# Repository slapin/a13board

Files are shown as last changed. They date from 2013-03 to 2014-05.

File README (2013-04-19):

Copyright (C) 2013 Sergey Lapin

These schematics and PCB layout are free: you can redistribute it
and/or modify it under the terms of the GNU General Public License
as published by the Free Software Foundation, either version 3
of the License, or (at your option) any later version.

This schematic and PCB layout are distributed in the hope that these
will be useful, but WITHOUT ANY WARRANTY; without even the implied
warranty of MERCHANTABILITY or FITNESS FOR A PARTICULAR PURPOSE.
See the GNU General Public License for more details.

You should have received a copy of the GNU General Public License
along with this program.  If not, see <http://www.gnu.org/licenses/>.

Please note, that this license is only for schematics and board layout,
and symbol libraries.
I don't know, and I don't want to know of any patent issues you can get
into using this design. Good luck.

Also, `sexpdata` is licensed under the terms of the BSD 2-Clause License.
See the source code for more information.

Symbol for Allwinner A13 was taken from Olimex PCB for OLinuXino,
and is subject to their license and permissions.
See https://github.com/OLIMEX/OLINUXINO

S.

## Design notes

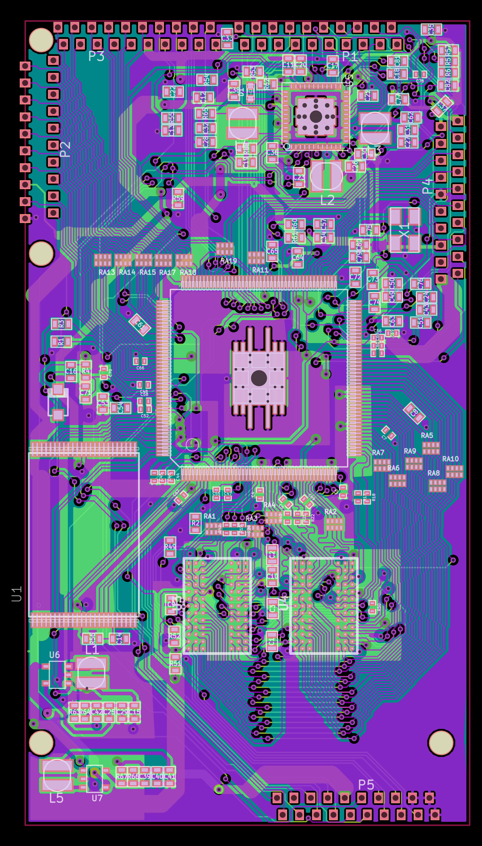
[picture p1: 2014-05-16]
png/pcb.png

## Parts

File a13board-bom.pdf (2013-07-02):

a13board.csv

Page 1

Идентификатор Элемент Корпус | Количество | Номинал
1 P6,P9,P7,P81pin | 4 CONN_1
2 D2 | SOD123 | 1 1N5819(S4SOD-123)
3 D1 | LED-0603 | 1 LED/0603
4 C3,C2,C1 SM0603_Capa | 3 100nF
5 U6,U7 | SOT23-5 | 2 SY8008BAAC
6 L5,L1,L2,L4,L3CD32 | 5 2.2uH/1.5A/DCR<0.1R/CD32
7 R17,R18,R19,R20,R22,R42,R43,R2 SM0402 | 8 22R
8 R50 | SM0402 | 1 240R/1%
9 C5,C6,C60,C61,C56,C69,C52,C45 SM0402 | 13 100nF
10 C78,C59,C68,C46,C48 SM0402 | 5 10uF/6.3V
11 C66,C58,C44SM0402 | 3 22uF/6.3V
12 C70 | SM0402 | 1 1uF
13 X1 | C5032 | 1 CRYSTAL4
14 C53,C20,C38,C13,C12,C11,C82,C SM0603A | 21 10uF/6.3V
15 C16 | SM0603A | 1 NA(22uF/6.3V)
16 C15,C10,C9,C81,C8,C54,C65,C64 SM0603A | 12 100nF
17 C14 | SM0603A | 1 NA(100nF)
18 C18,C17,C51,C32 SM0603A | 4 1uF
19 C19,C74,C72,C75,C73,C30,C31,C SM0603A | 8 1nF
20 C79,C80 | SM0603A | 2 33pF
21 C77 | SM0603A | 1 3.3nF
22 C63,C40,C41,C29,C42 SM0603A | 5 22uF/6.3V
23 C39 | SM0603A | 1 22pF
24 C25 | SM0603A | 1 47pF
25 R66 | SM0603A | 1 3.3k/1%
26 R56 | SM0603A | 1 NA(10k)
27 R62,R6,R5,R59,R60,R61,R58 SM0603A | 7 2.2k
28 R49,R53,R2 SM0603A | 3 240R/1%
29 R67 | SM0603A | 1 4.99k/1%
30 R3,R4 | SM0603A | 2 47k
31 R55,R54 | SM0603A | 2 1R
32 R1,R57 | SM0603A | 2 200k/1%
33 R65 | SM0603A | 1 0.03R/1%
34 R64 | SM0603A | 1 100k/1%
35 R63 | SM0603A | 1 22k/1%
36 R51,R52 | SM0603A | 2 2k/1%
37 P4,P2,P3,P5,P1 CONN20-1.27zzz | 5 CONN_20
38 U2 | allwinner_a13-OLIMEX_IC_TQFP176 | 1 A13
39 RA1,RA18,RA17,RA15,RA14,RA13, RN4x0402 | 17 RA4X0402
40 U1 | TSOP48 | 1 H27UBG8T2A/TSOP48
41 U4,U3 | BGA78 | 2 H5TQ2G43CFR
42 U5 | QFN48+1 | 1 OLIMEX_IC_AXP209

a13board.csv

Page 2

Supplier and ref

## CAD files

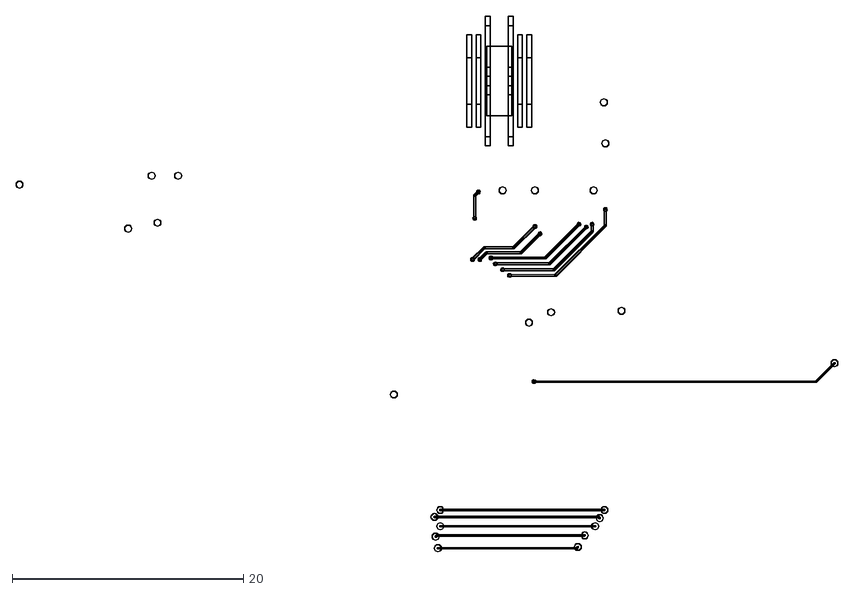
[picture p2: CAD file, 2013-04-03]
dxf/a13board-B_Cu.dxf
71.1 x 46.3

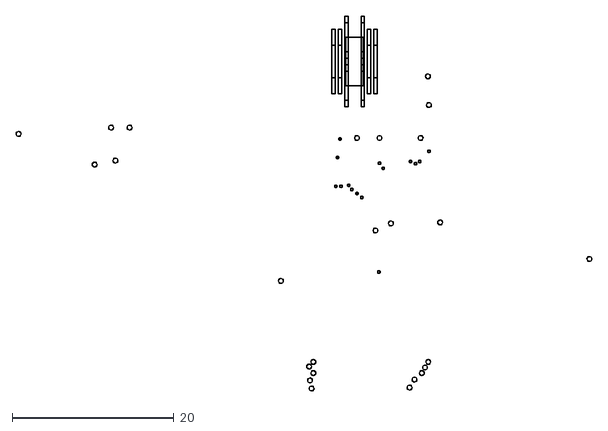
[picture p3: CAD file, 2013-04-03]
dxf/a13board-Inner2_Cu.dxf
71.1 x 46.3

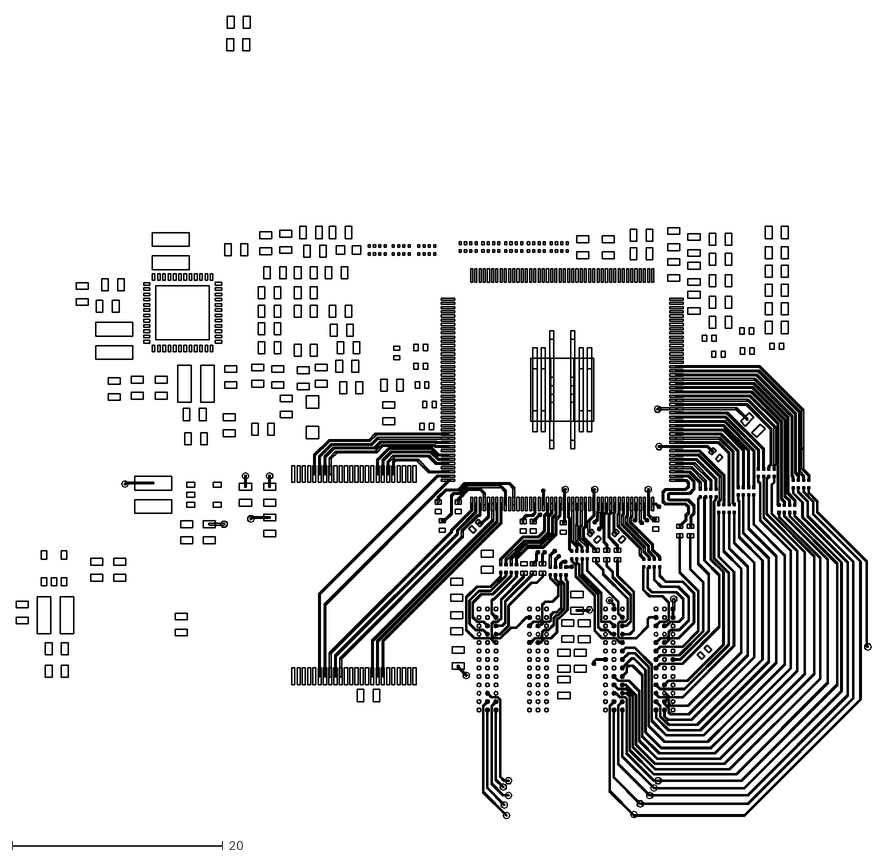
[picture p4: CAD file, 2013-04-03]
dxf/a13board-F_Cu.dxf
81.1 x 76.1

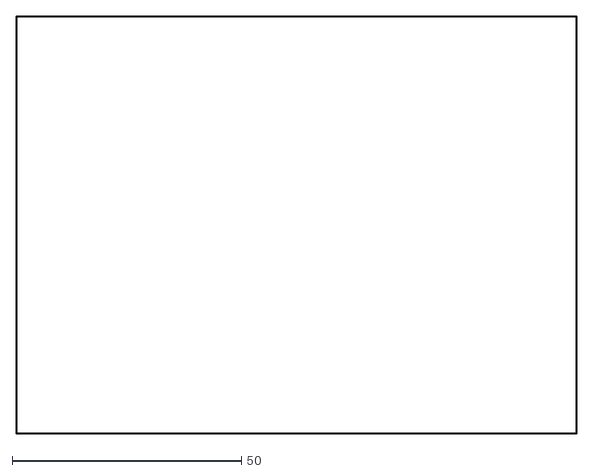
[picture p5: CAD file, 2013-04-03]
dxf/a13board-Edge_Cuts.dxf
122.5 x 91.2

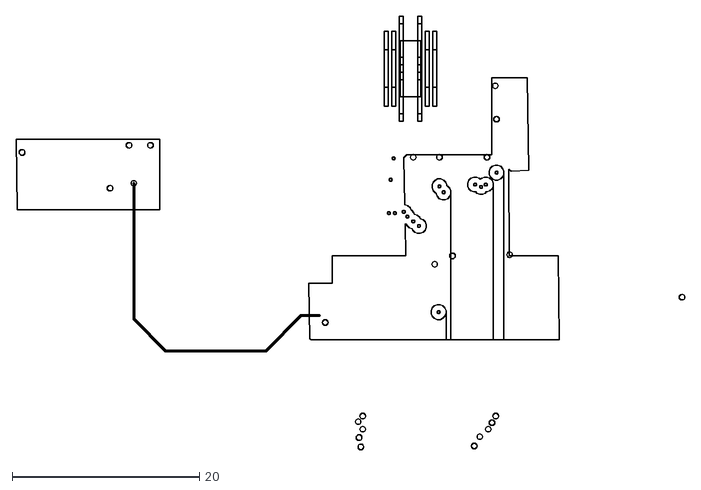
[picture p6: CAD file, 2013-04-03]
dxf/a13board-Inner1_Cu.dxf
71.4 x 46.3

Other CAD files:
dxf/a13board-F_SilkS.dxf

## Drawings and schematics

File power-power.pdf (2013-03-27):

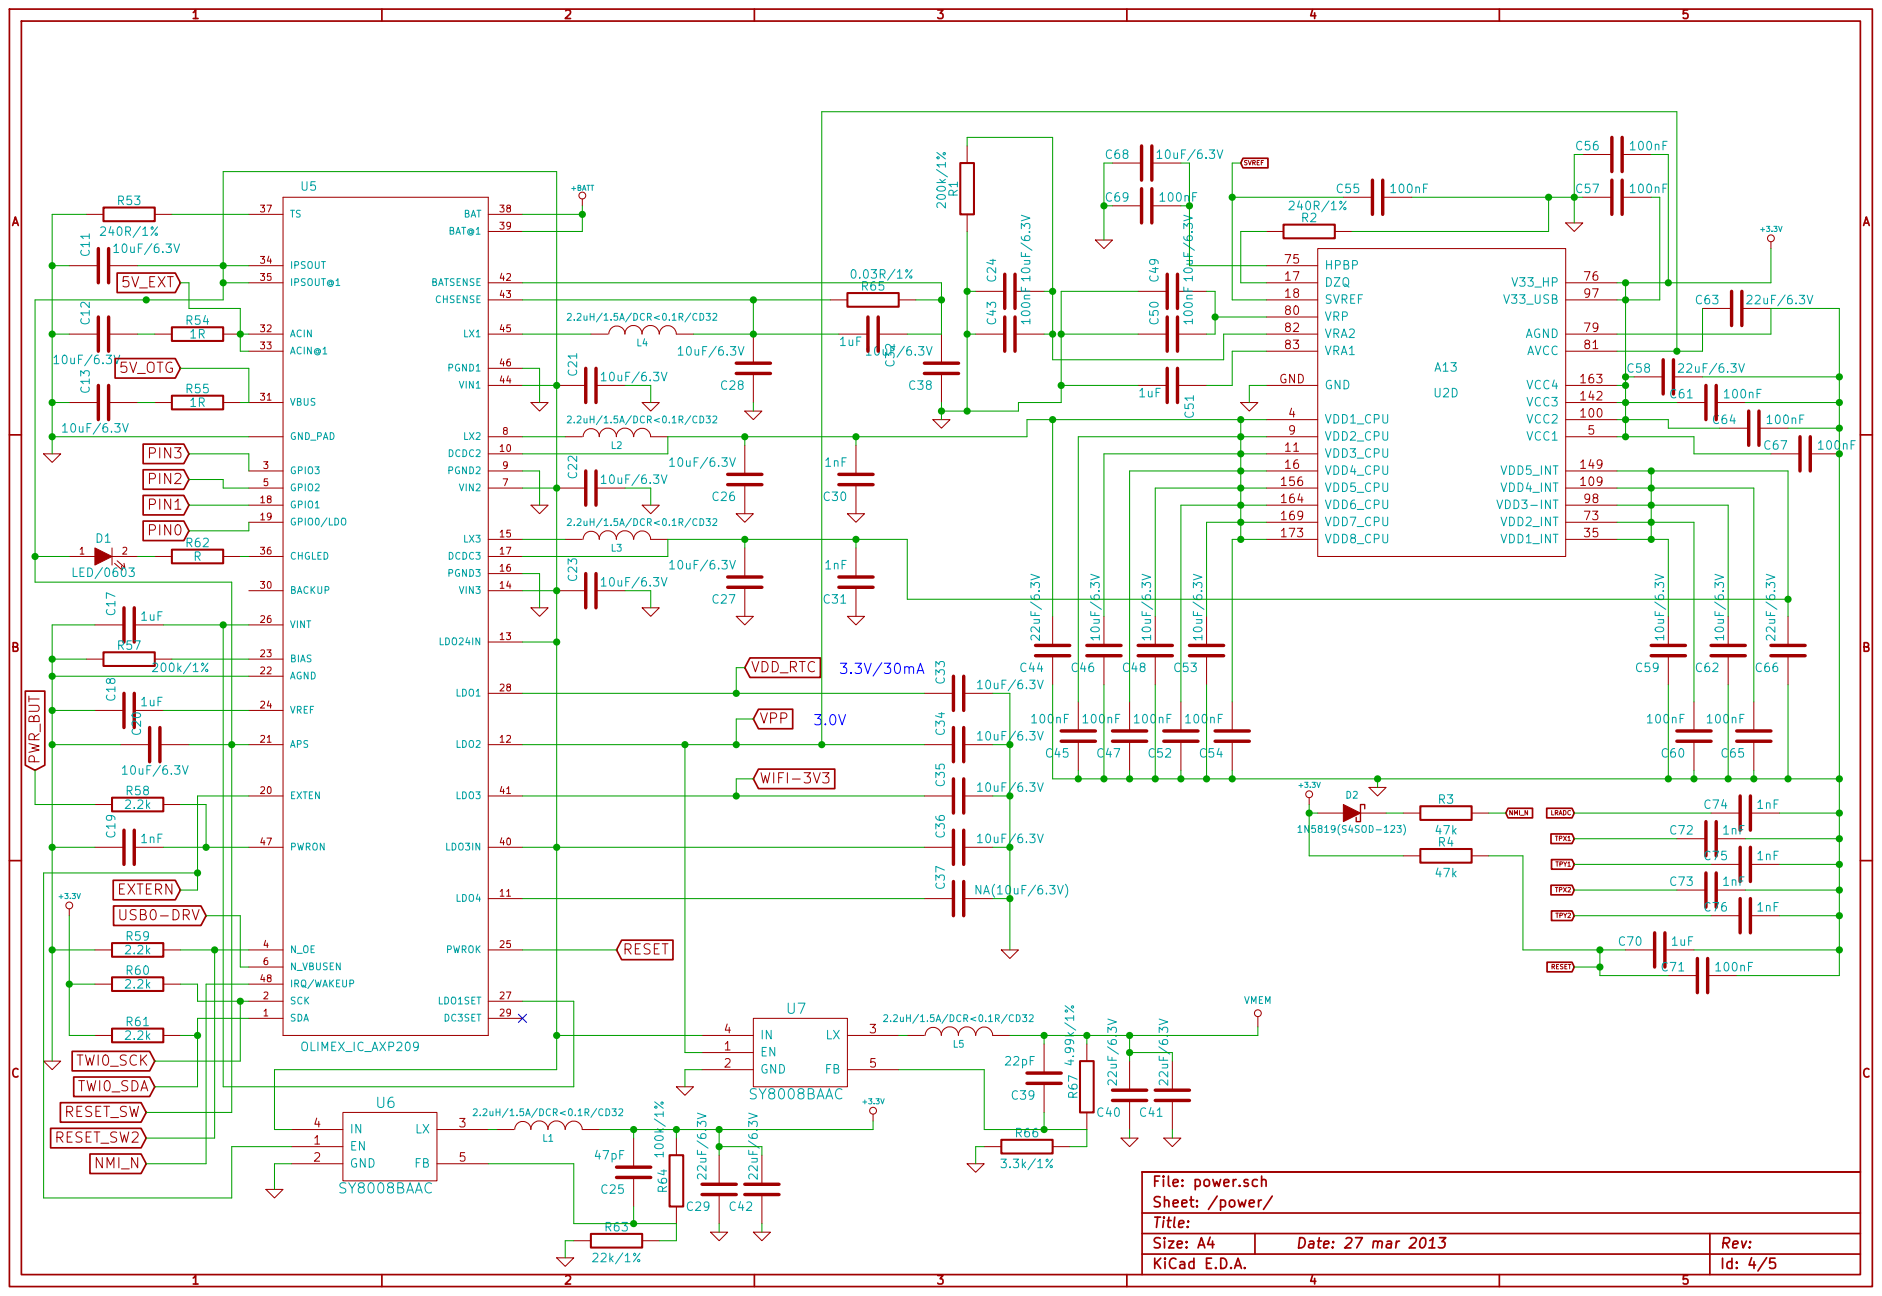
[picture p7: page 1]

RESET

EN 1 GND 2

Id: 4/5 Title: File: power.sch

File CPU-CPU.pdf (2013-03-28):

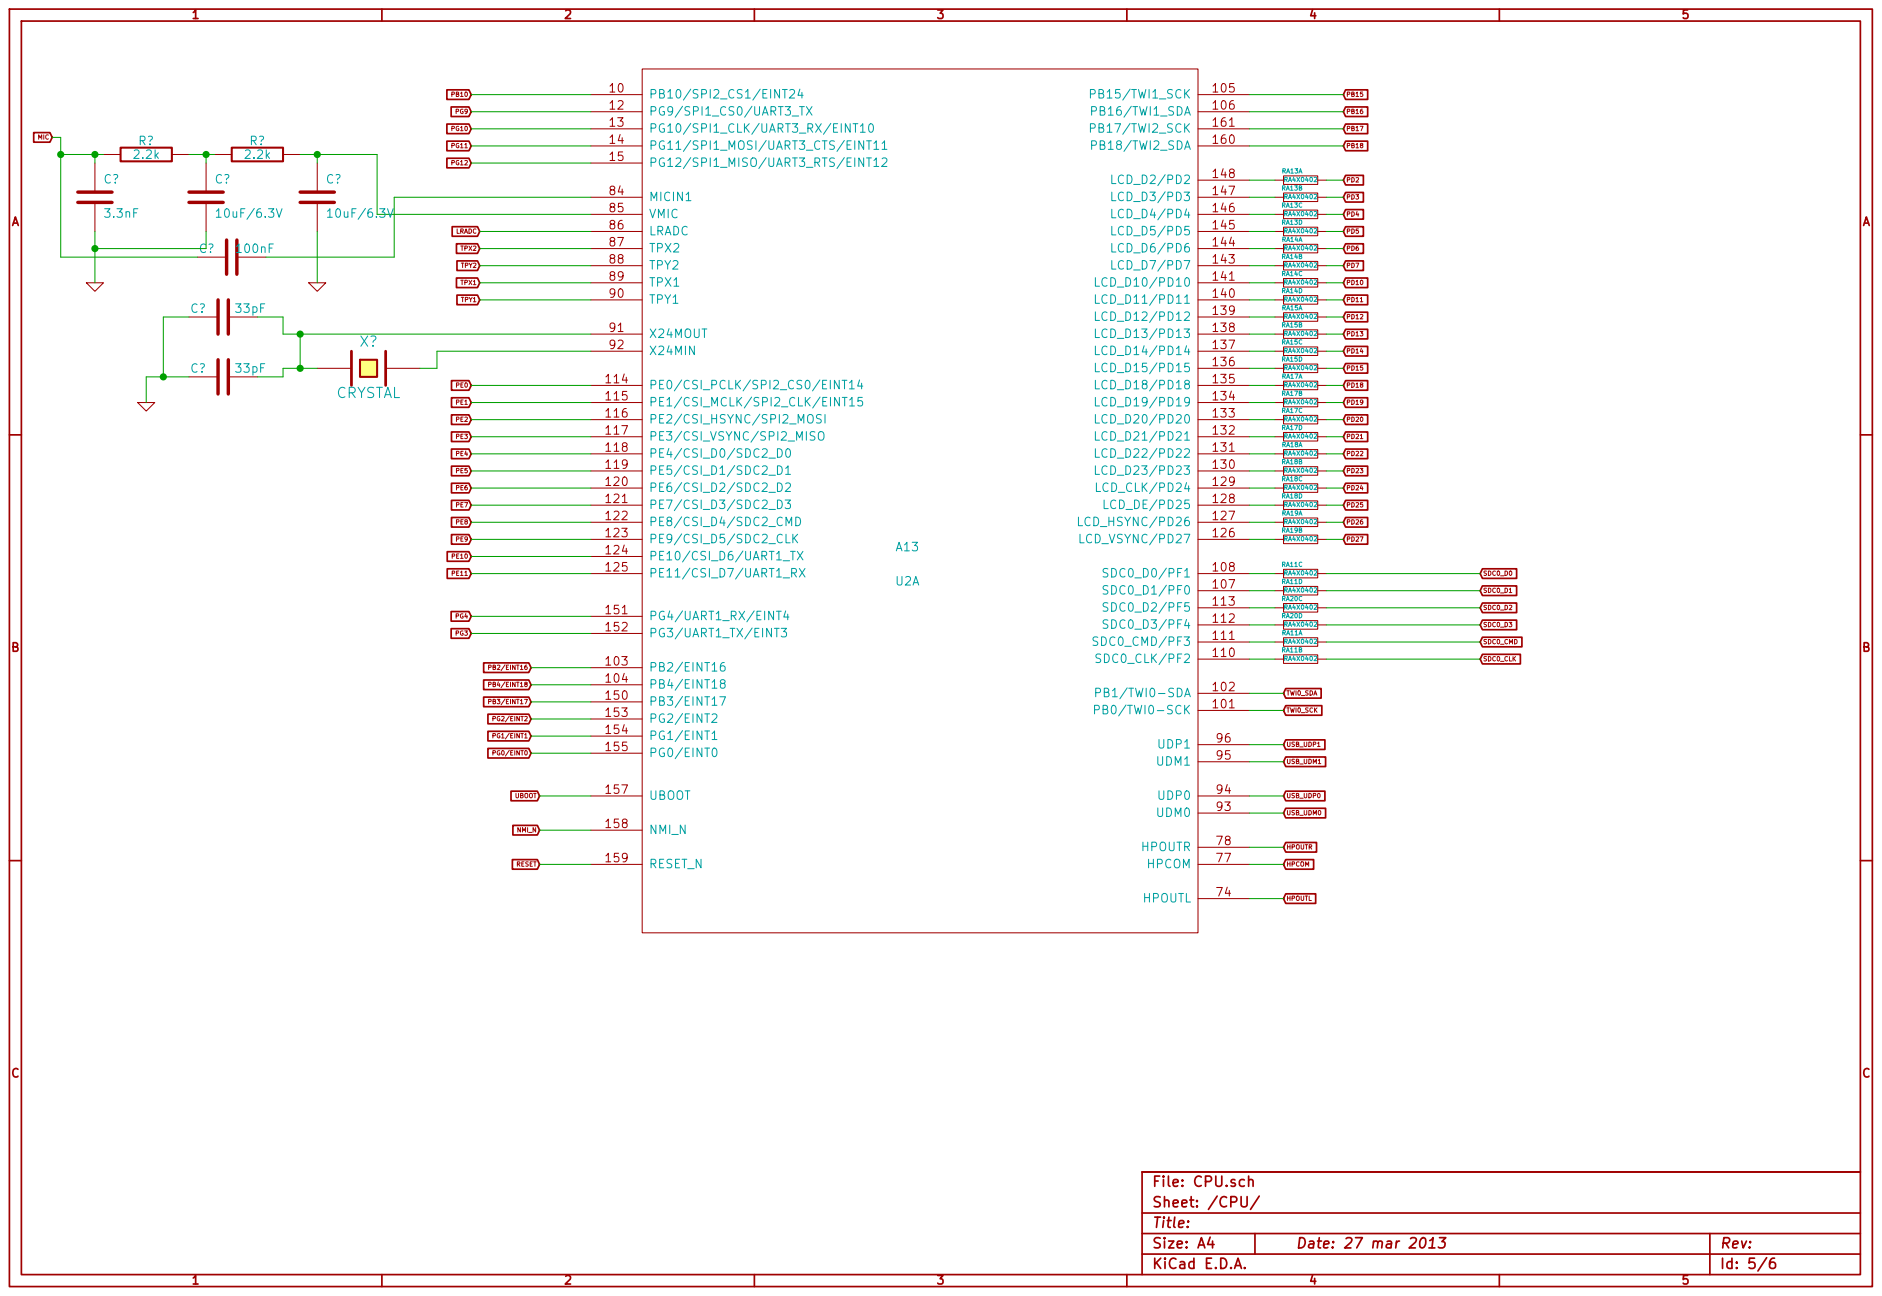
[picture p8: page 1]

Id: 5/6 Title: File: CPU.sch
Sheet: /CPU/

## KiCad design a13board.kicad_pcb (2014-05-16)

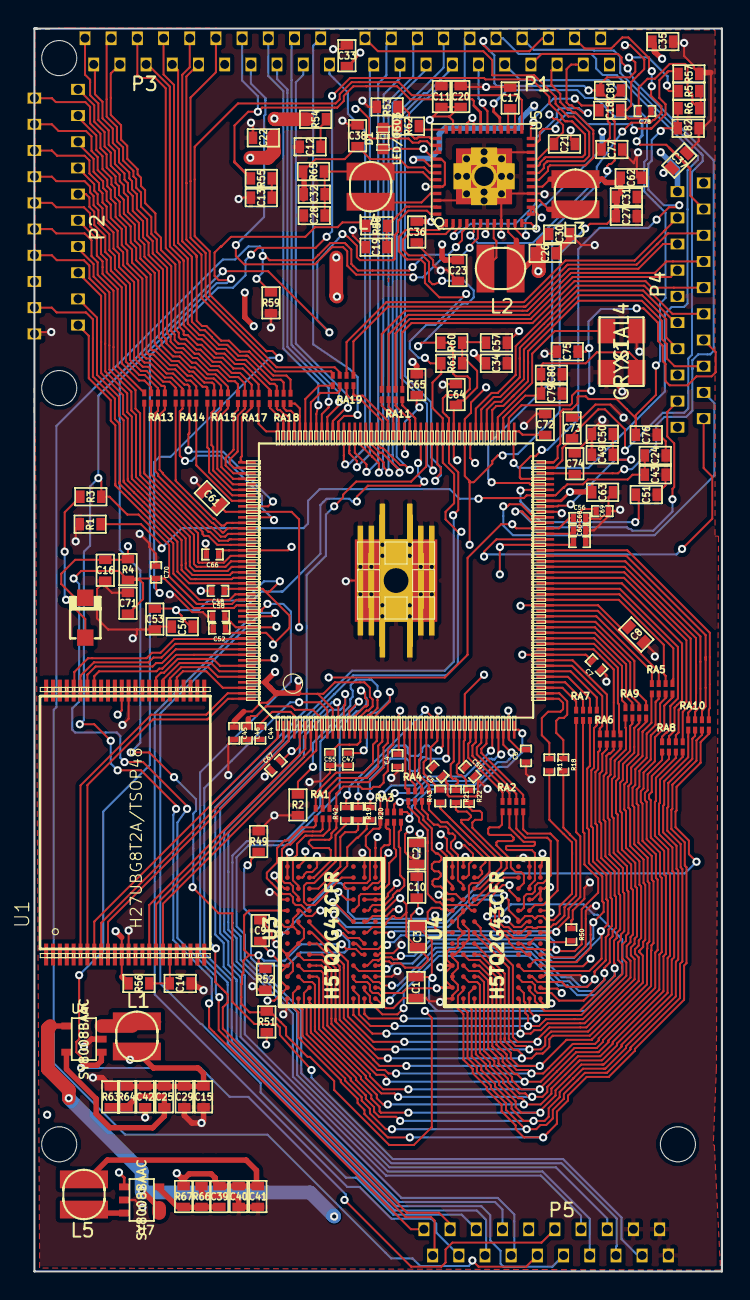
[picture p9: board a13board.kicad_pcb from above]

Board: 4 copper layers, 50.0 x 90.4 mm, 156 parts (0 on the bottom side), 271 nets.

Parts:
1PIN, 1PIN#2, 1PIN#3, 1PIN#4: P***; 1pin
C1, C2, C3: 100nF; SM0603_Capa
C4, C5, C6, C7, C45, C47, C52, C55, C56, C60, C67, C69: 100nF; SM0402
C8, C9, C10, C15, C43, C50, C54, C57, C64, C65, C71, C81: 100nF; SM0603A
C11, C12, C13, C20, C21, C22, C23, C24, C26, C27, C28, C33, C34, C35, C36, C37, C38, C49, C53, C62, C82: 10uF/6.3V; SM0603A
C14: NA(100nF); SM0603A
C16: NA(22uF/6.3V); SM0603A
C17, C18, C32, C51: 1uF; SM0603A
C19, C30, C31, C72, C73, C74, C75, C76: 1nF; SM0603A
C25: 47pF; SM0603A
C29, C40, C41, C42, C63: 22uF/6.3V; SM0603A
C39: 22pF; SM0603A
C44, C58, C66: 22uF/6.3V; SM0402
C46, C48, C59, C68, C78: 10uF/6.3V; SM0402
C61: 100nF; SM0603
C70: 1uF; SM0402
C77: 3.3nF; SM0603A
C79, C80: 33pF; SM0603A
D1: LED/0603; LED-0603
D2: 1N5819(S4SOD-123); SOD123
L1, L2, L3, L4, L5: 2.2uH/1.5A/DCR<0.1R/CD32; CD32
P1, P2, P3, P4, P5: CONN_20; CONN20-1.27zzz
R1, R57: 200k/1%; SM0603A
R2, R49, R53: 240R/1%; SM0603A
R3, R4: 47k; SM0603A
R5, R6, R58, R59, R60, R61, R62: 2.2k; SM0603A
R17, R18, R19, R20, R21, R22, R42, R43: 22R; SM0402
R50: 240R/1%; SM0402
R51, R52: 2k/1%; SM0603A
R54, R55: 1R; SM0603A
R56: NA(10k); SM0603A
R63: 22k/1%; SM0603A
R64: 100k/1%; SM0603A
R65: 0.03R/1%; SM0603A
R66: 3.3k/1%; SM0603A
R67: 4.99k/1%; SM0603A
RA1, RA2, RA3, RA4, RA5, RA6, RA7, RA8, RA9, RA10, RA11, RA13, RA14, RA15, RA17, RA18, RA19: RA4X0402; RN4x0402
U1: H27UBG8T2A/TSOP48; TSOP48
U2: A13; allwinner_a13-OLIMEX_IC_TQFP176
U3, U4: H5TQ2G43CFR; BGA78
U5: OLIMEX_IC_AXP209; QFN48+1
U6, U7: SY8008BAAC; SOT23-5
X1: CRYSTAL4; C5032

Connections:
5V_EXT: P3.9, R54.2, U5.32, U5.33
5V_OTG: P3.8, R55.2, U5.31
+3.3V: C15.1, C16.1, C25.2, C29.2, C42.2, C56.2, C57.2, C58.1, C61.1, C64.1, C67.1, D2.1, L1.2, P4.1, R4.1, R56.1, R60.1, R61.1, R64.2, U1.12, U1.37, U2.5, U2.76, U2.97, U2.100, U2.142, U2.163
+BATT: P1.20, U5.38, U5.39
/DRAM/CPU_A0: RA5.1, U2.64
/DRAM/CPU_A1: RA6.3, U2.52
/DRAM/CPU_A2: RA8.3, U2.66
/DRAM/CPU_A3: RA8.4, U2.65
/DRAM/CPU_A4: RA6.4, U2.51
/DRAM/CPU_A5: RA8.2, U2.67
/DRAM/CPU_A6: RA6.2, U2.54
/DRAM/CPU_A7: RA10.2, U2.71
/DRAM/CPU_A8: RA6.1, U2.55
/DRAM/CPU_A9: RA10.4, U2.69
/DRAM/CPU_A10: RA7.3, U2.48
/DRAM/CPU_A11: RA9.4, U2.56
/DRAM/CPU_A12: RA7.1, U2.50
/DRAM/CPU_A13: RA8.1, U2.68
/DRAM/CPU_A14: RA9.3, U2.57
/DRAM/CPU_BA0: RA5.2, U2.63
/DRAM/CPU_BA1: RA7.2, U2.49
/DRAM/CPU_BA2: RA5.3, U2.61
/DRAM/CPU_CAS: RA9.1, U2.59
/DRAM/CPU_CK: R17.2, U2.45
/DRAM/CPU_CKE: RA7.4, U2.47
/DRAM/CPU_CK_N: R18.2, U2.46
/DRAM/CPU_D0: RA1.1, U2.22
/DRAM/CPU_D1: RA3.4, U2.40
/DRAM/CPU_D2: RA1.2, U2.21
/DRAM/CPU_D3: RA3.3, U2.41
/DRAM/CPU_D4: RA1.4, U2.19
/DRAM/CPU_D5: RA3.1, U2.44
/DRAM/CPU_D6: RA1.3, U2.20
/DRAM/CPU_D7: RA3.2, U2.42
/DRAM/CPU_D8: RA2.3, U2.37
/DRAM/CPU_D9: RA4.3, U2.25
/DRAM/CPU_D10: RA2.1, U2.39
/DRAM/CPU_D11: RA4.4, U2.24
/DRAM/CPU_D12: RA2.4, U2.36
/DRAM/CPU_D13: RA4.2, U2.26
/DRAM/CPU_D14: RA2.2, U2.38
/DRAM/CPU_D15: RA4.1, U2.27
/DRAM/CPU_DM0: R42.1, U2.29
/DRAM/CPU_DM1: R43.1, U2.28
/DRAM/CPU_DQS0: R19.2, U2.31
/DRAM/CPU_DQS0_N: R20.2, U2.32
/DRAM/CPU_DQS1: R21.2, U2.33
/DRAM/CPU_DQS1_N: R22.2, U2.34
/DRAM/CPU_MEMRST: RA10.3, U2.70
/DRAM/CPU_ODT: RA10.1, U2.72
/DRAM/CPU_RAS: RA9.2, U2.58
/DRAM/CPU_WE: RA5.4, U2.60
/DRAM/DDR3_A0: RA5.8, U3.K3, U4.K3
/DRAM/DDR3_A1: RA6.6, U3.L7, U4.L7
/DRAM/DDR3_A2: RA8.6, U3.L3, U4.L3
/DRAM/DDR3_A3: RA8.5, U3.K2, U4.K2
/DRAM/DDR3_A4: RA6.5, U3.L8, U4.L8
/DRAM/DDR3_A5: RA8.7, U3.L2, U4.L2
/DRAM/DDR3_A6: RA6.7, U3.M8, U4.M8
/DRAM/DDR3_A7: RA10.7, U3.M2, U4.M2
/DRAM/DDR3_A8: RA6.8, U3.N8, U4.N8
/DRAM/DDR3_A9: RA10.5, U3.M3, U4.M3
/DRAM/DDR3_A10: RA7.6, U3.H7, U4.H7
/DRAM/DDR3_A11: RA9.5, U3.M7, U4.M7
/DRAM/DDR3_A12: RA7.8, U3.K7, U4.K7
/DRAM/DDR3_A13: RA8.8, U3.N3, U4.N3
/DRAM/DDR3_A14: RA9.6, U3.N7, U4.N7
/DRAM/DDR3_BA0: RA5.7, U3.J2, U4.J2
/DRAM/DDR3_BA1: RA7.7, U3.K8, U4.K8
/DRAM/DDR3_BA2: RA5.6, U3.J3, U4.J3
/DRAM/DDR3_CAS: RA9.8, U3.G3, U4.G3
/DRAM/DDR3_CK: R17.1, U3.F7, U4.F7
/DRAM/DDR3_CKE: RA7.5, U3.G9, U4.G9
/DRAM/DDR3_CK_N: R18.1, U3.G7, U4.G7
/DRAM/DDR3_D0: RA1.8, U3.B3
/DRAM/DDR3_D1: RA3.5, U3.C7
/DRAM/DDR3_D2: RA1.7, U3.C2
/DRAM/DDR3_D3: RA3.6, U3.C8
/DRAM/DDR3_D4: RA1.5, U3.E3
/DRAM/DDR3_D5: RA3.8, U3.E8
/DRAM/DDR3_D6: RA1.6, U3.D2
/DRAM/DDR3_D7: RA3.7, U3.E7
/DRAM/DDR3_D8: RA2.6, U4.C8
/DRAM/DDR3_D9: RA4.6, U4.D2
/DRAM/DDR3_D10: RA2.8, U4.E8
/DRAM/DDR3_D11: RA4.5, U4.E3
/DRAM/DDR3_D12: RA2.5, U4.C7
/DRAM/DDR3_D13: RA4.7, U4.C2
/DRAM/DDR3_D14: RA2.7, U4.E7
/DRAM/DDR3_D15: RA4.8, U4.B3
/DRAM/DDR3_DM0: R42.2, U3.B7
/DRAM/DDR3_DM1: R43.2, U4.B7
/DRAM/DDR3_DQS0: R19.1, U3.C3
/DRAM/DDR3_DQS0_N: R20.1, U3.D3
/DRAM/DDR3_DQS1: R21.1, U4.C3
/DRAM/DDR3_DQS1_N: R22.1, U4.D3
/DRAM/DDR3_ODT: RA10.8, U3.G1, U4.G1
/DRAM/DDR3_RAS: RA9.7, U3.F3, U4.F3
/DRAM/DDR3_RST: RA10.6, U3.N2, U4.N2
/DRAM/DDR3_WE: RA5.5, U3.H3, U4.H3
/NAND/NALE: U1.17, U2.7
/NAND/NAND_WP: C14.1, R56.2, U1.19
/NAND/NCE0: U1.9, U2.2
/NAND/NCE1: U1.10, U2.3
/NAND/NCLE: U1.16, U2.6
/NAND/NDQ0: U1.29, U2.174
/NAND/NDQ1: U1.30, U2.172
/NAND/NDQ2: U1.31, U2.171
/NAND/NDQ3: U1.32, U2.170
/NAND/NDQ4: U1.41, U2.168
/NAND/NDQ5: U1.42, U2.167
/NAND/NDQ6: U1.43, U2.166
/NAND/NDQ7: U1.44, U2.165
/NAND/NRB0: U1.7, U2.176
/NAND/NRB1: U1.6, U2.175
/NAND/NRE: U1.8, U2.1
/NAND/NWE: U1.18, U2.8
/power/VDD_CPU: C26.2, C30.2, C44.2, C45.2, C46.2, C47.2, C48.2, C52.2, C53.2, C54.2, L2.2, U2.4, U2.9, U2.11, U2.16, U2.156, U2.164, U2.169, U2.173, U5.10
/power/VDD_INT: C27.2, C31.2, C59.2, C60.2, C62.2, C65.2, C66.2, L3.2, U2.35, U2.73, U2.98, U2.109, U2.149, U5.17
BACKUP: P1.10, U5.30
EXTEN: P5.10, U5.20, U6.1
GND: C1.2, C2.2, C4.2, C5.2, C6.2, C7.2, C8.2, C9.2, C10.2, C11.1, C12.1, C13.1, C14.2, C15.2, C16.2, C17.1, C18.1, C19.1, C20.1, C21.2, C22.2, C23.2, C24.1, C26.1, C27.1, C28.1, C29.1, C30.1, C31.1, C33.2, C34.2, C35.2, C36.2, C37.2, C38.1, C40.1, C41.1, C42.1, C43.1, C44.1, C45.1, C46.1, C47.1, C48.1, C49.1, C50.1, C51.2, C52.1, C53.1, C54.1, C55.2, C56.1, C57.1, C58.2, C59.1, C60.1, C61.2, C62.1, C63.2, C64.2, C65.1, C66.1, C67.2, C68.1, C69.1, C70.2, C71.2, C72.2, C73.2, C74.2, C75.2, C76.2, C77.2, C78.2, C79.1, C80.1, C82.2, P2.1, P4.11, P5.1, P5.2, P5.4, R1.1, R2.2, R49.2, R50.2, R52.2, R53.1, R57.1, R59.1, R63.1, R66.1, U1.13, U1.36, U2.79, U2.GND, U3.A1, U3.A8, U3.B1, U3.B2, U3.B8, U3.C9, U3.D1, U3.D8, U3.D9, U3.F2, U3.F8, U3.H2, U3.J1, U3.J9, U3.L1, U3.L9, U3.N1, U3.N9, U4.A1, U4.A8, U4.B1, U4.B2, U4.B8, U4.C9, U4.D1, U4.D8, U4.D9, U4.F2, U4.F8, U4.H2, U4.J1, U4.J9, U4.L1, U4.L9, U4.N1, U4.N9, U5.9, U5.16, U5.22, U5.46, U5.GND, U6.2, U7.2, X1.2, X1.4
HPCOM: P4.3, U2.77
HPOUTL: P4.2, U2.74
HPOUTR: P4.4, U2.78
IPSOUT: C11.2, C20.2, C21.1, C22.1, C23.1, C36.1, D1.1, P4.5, P5.12, U5.7, U5.13, U5.14, U5.21, U5.34, U5.35, U5.40, U5.44, U6.4, U7.4
LDO4_3V3_200MA: C37.1, P4.20, U5.11
LRADC: C74.1, P1.14, U2.86
MIC: C77.1, C81.1, P1.15, R5.1
unnamed: R50.1, U4.H8
unnamed: R49.1, U3.H8
unnamed: C1.1, C2.1, C3.2, C10.1, R51.2, R52.1, U3.E1, U3.J8, U4.E1, U4.J8
unnamed: L1.1, U6.3
unnamed: L5.1, U7.3
unnamed: C25.1, R63.2, R64.1, U6.5
unnamed: C39.1, R66.2, R67.1, U7.5
unnamed: C68.2, C69.2, U2.75
unnamed: D2.2, R3.1
unnamed: C32.1, C38.2, R65.2, U5.42
unnamed: C49.2, C50.2, U2.80
unnamed: C24.2, C43.2, R1.2, U2.82
unnamed: R2.1, U2.17
unnamed: C51.1, U2.83
unnamed: L3.1, U5.15
unnamed: L4.1, U5.45
unnamed: C17.2, U5.26, U5.27
unnamed: R53.2, U5.37
unnamed: L2.1, U5.8
unnamed: R62.2, U5.36
unnamed: C12.2, R54.1
unnamed: C13.2, R55.1
unnamed: D1.2, R62.1
unnamed: R57.2, U5.23
unnamed: C18.2, U5.24
unnamed: C28.2, C32.2, L4.2, R65.1, U5.43
unnamed: C19.2, R58.2, U5.47
unnamed: RA11.1, U2.111
unnamed: RA14.3, U2.141
unnamed: RA14.2, U2.143
unnamed: RA14.1, U2.144
unnamed: RA13.4, U2.145
unnamed: RA13.3, U2.146
unnamed: RA13.2, U2.147
unnamed: RA13.1, U2.148
unnamed: RA14.4, U2.140
unnamed: RA11.2, U2.110
unnamed: RA19.1, U2.127
unnamed: RA19.2, U2.126
unnamed: RA15.1, U2.139
unnamed: RA18.4, U2.128
unnamed: RA18.3, U2.129
unnamed: RA18.2, U2.130
unnamed: RA18.1, U2.131
unnamed: RA17.4, U2.132
unnamed: RA17.3, U2.133
unnamed: RA17.2, U2.134
unnamed: RA17.1, U2.135
unnamed: RA15.4, U2.136
unnamed: RA15.3, U2.137
unnamed: RA15.2, U2.138
unnamed: C79.2, C80.2, U2.91, X1.1
unnamed: RA19.3, U2.113
unnamed: RA11.4, U2.107
unnamed: RA11.3, U2.108
unnamed: RA19.4, U2.112
unnamed: C81.2, U2.84
unnamed: C78.1, R5.2, R6.1
unnamed: C82.1, R6.2, U2.85
unnamed: U2.92, X1.3
NMI_N: P5.20, R3.2, U2.158, U5.48
PB2: P1.9, U2.103
PB3: P2.9, U2.150
PB4: P1.8, U2.104
PB10: P5.9, U2.10
PB15: P5.18, U2.105
PB16: P5.17, U2.106
PB17: P5.16, U2.161
PB18: P5.15, U2.160
PD2: P2.10, RA13.8
PD3: P2.11, RA13.7
PD4: P2.12, RA13.6
PD5: P2.13, RA13.5
PD6: P2.14, RA14.8
PD7: P2.15, RA14.7
PD10: P2.16, RA14.6
PD11: P2.17, RA14.5
PD12: P2.18, RA15.8
PD13: P2.19, RA15.7
PD14: P2.20, RA15.6
PD15: P3.20, RA15.5
PD18: P3.19, RA17.8
PD19: P3.18, RA17.7
PD20: P3.17, RA17.6
PD21: P3.16, RA17.5
PD22: P3.15, RA18.8
PD23: P3.14, RA18.7
PD24: P3.13, RA18.6
PD25: P3.12, RA18.5
PD26: P3.11, RA19.8
PD27: P3.10, RA19.7
PE0: P1.7, U2.114
PE1: P1.6, U2.115
PE2: P1.5, U2.116
PE3: P1.4, U2.117
PE4: P1.3, U2.118
PE5: P1.2, U2.119
PE6: P3.1, U2.120
PE7: P3.2, U2.121
PE8: P3.3, U2.122
PE9: P3.4, U2.123
PE10: P3.5, U2.124
PE11: P3.6, U2.125
PG0: P2.3, U2.155
PG1: P2.4, U2.154
PG2: P2.6, U2.153
PG3: P2.7, U2.152
PG4: P2.8, U2.151
PG9: P5.8, U2.12
PG10: P5.7, U2.13
PG11: P5.6, U2.14
PG12: P5.5, U2.15
PIN0: P1.1, U5.19
PIN1: P1.16, U5.18
PIN2: P1.17, U5.5
PIN3: P1.18, U5.3
PWR_BUT: P5.3, R58.1
RESET: C70.1, C71.1, P5.19, R4.2, U2.159, U5.25
RESET_SW2: P5.11, R59.2, U5.4
SDC0_CLK: P4.14, RA11.7
SDC0_CMD: P4.15, RA11.8
SDC0_D0: P4.13, RA11.6
SDC0_D1: P4.12, RA11.5
SDC0_D2: P4.17, RA19.6
SDC0_D3: P4.16, RA19.5
SVREF: C55.1, U2.18
TPX1: C72.1, P1.11, U2.89
TPX2: C73.1, P1.13, U2.87
TPY1: C75.1, P4.8, U2.90
TPY2: C76.1, P1.12, U2.88
TWI0_SCK: P5.14, R60.2, U2.101, U5.2
TWI0_SDA: P5.13, R61.2, U2.102, U5.1
UBOOT: P2.2, U2.157
USB0-DRV: P3.7, U5.6
USB_UDM0: P4.6, U2.93
USB_UDM1: P4.9, U2.95
USB_UDP0: P4.7, U2.94
USB_UDP1: P4.10, U2.96
VDD_RTC: C33.1, P4.18, U5.28
VMEM: C3.1, C4.1, C5.1, C6.1, C7.1, C8.1, C9.1, C39.2, C40.2, C41.2, L5.2, R51.1, R67.2, U2.23, U2.30, U2.43, U2.53, U2.62, U3.A2, U3.A9, U3.B9, U3.C1, U3.D7, U3.E2, U3.E9, U3.G2, U3.G8, U3.K1, U3.K9, U3.M1, U3.M9, U4.A2, U4.A9, U4.B9, U4.C1, U4.D7, U4.E2, U4.E9, U4.G2, U4.G8, U4.K1, U4.K9, U4.M1, U4.M9
VPP: C34.1, C63.1, P2.5, U2.81, U5.12, U7.1
WIFI-3V3: C35.1, P4.19, U5.41

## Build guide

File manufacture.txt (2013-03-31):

http://www.aliexpress.com/item/4-Layers-PCB-prototypes-printed-circuit-board-fabrication-10pcs-lot-Max-10cm-10cm-free-shipping-1045/483958869.html
$99

Place of Origin:
    Guangdong China (Mainland)

Min. Hole Size:
    0.3mm

Number of Layers:
    4-Layer

Model Number:
    4L

Min. Line Width:
    5mil

Brand Name:
    DIYGSM

is_customized:
    Yes

Base Material:
    FR4

Min. Line Spacing:
    5mil

Board Thickness:
    0.8-2.0 mm

Surface Finishing:
    HASL

Copper Thickness:
    1-4 OZ 

http://www.aliexpress.com/item/4-Layers-PCB-prototypes-printed-circuit-board-fabrication-10pcs-lot-Max-10cm-10cm-free-shipping-1045/460137153.html
$99

 Process	4 mil trace/space, 0.3mm hole

 Layers	4 layers
 Material	 FR4 0.062" FR4 1 oz
 Finishing	 HASL
 Soldermask	 Green LPI SMOBC
 Silkscreen	 White
 Lead time 	 3-4 work days

    Maximum 10cmx10cm area for 1 or 2 layers

    Additional charge for bottom silkscreen.

    3-4 work days leadtime

Place of Origin:
    China (Mainland)

Min. Hole Size:
    0.3mm

Min. Line Width:
    6mil

Brand Name:
    Red Board

Base Material:
    FR4

Min. Line Spacing:
    6mil

Board Thickness:
    0.8-1.6 mm

Surface Finishing:
    HASL

Copper Thickness:
    1-4 OZ 

quote: tedchen163@yahoo.com

http://www.aliexpress.com/item/PCB-board-Alunimium-based-PCB-pcb-manufacture-PCB-prototype-free-shippment-rigid-PCB/430062534.html
quote luwispcb(at)gmail.com

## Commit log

2013-03-19 Better pin placement
2013-03-19 Some more pin names
2013-03-19 added some schematics
    [DRAM.sch, NAND.sch, a13board.sch]
2013-03-20 Started drawing
    [DRAM.sch, NAND.sch, a13board.sch]
2013-03-20 Added more libraries; more advancement
    [DRAM.sch, NAND.sch, a13board.sch]
2013-03-20 still ERC errors
    [DRAM.sch, NAND.sch, a13board.sch]
2013-03-21 Proper laying out DDR3 in schematics
    [DRAM.sch, NAND.sch, a13board.sch]
2013-03-22 DDR3 is mostly captured
    [DRAM.sch, NAND.sch, a13board.sch]
2013-03-24 Finished DRAM, started power
    [DRAM.sch, NAND.sch, a13board.sch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]
2013-03-25 Power update; started CPU
    [CPU.sch, DRAM.sch, NAND.sch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]
2013-03-25 Fixed values for inductors
    [CPU.sch, DRAM.sch, NAND.sch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]
2013-03-26 added 3.3V power supply
    [CPU.sch, DRAM.sch, NAND.sch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]
2013-03-26 added resistor arrays, continue routing main CPU
    [CPU.sch, DRAM.sch, NAND.sch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]
2013-03-27 added schematic PDF
2013-03-27 Re-made A13 power part, finished power schematics
    [CPU.sch, DRAM.sch, NAND.sch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]
2013-03-28 Finished schematics, now fixing errors
    [CPU.sch, DRAM.sch, NAND.sch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]
2013-03-28 Added forgotten connectors.sch
    [connectors.sch]
2013-03-28 Added diode footprint
2013-03-28 Fixing schematics bugs
    [CPU.sch, DRAM.sch, NAND.sch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]
2013-03-28 Started making board and modules
    [a13board.kicad_pcb]
2013-03-29 fixed schematics errors, added CD32 and 4x0402 packages, started layout
    [a13board.kicad_pcb]
2013-03-29 Started tracing
    [a13board.kicad_pcb]
2013-03-31 more tracing progress
    [CPU.sch, DRAM.sch, NAND.sch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]
2013-04-01 Adding gerber files
    [a13board-B_Cu.gbl, a13board-F_Cu.gtl, a13board-F_SilkS.gto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]
2013-04-02 Re-tracing DDR3 with 4mil traces
    [a13board.kicad_pcb]
2013-04-03 Added dxf files
    [a13board-B_Cu.dxf, a13board-Edge_Cuts.dxf, a13board-F_Cu.dxf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]
2013-04-03 still routing ddr3
    [a13board.kicad_pcb]
2013-04-04 Routed ground poly and most of ddr3
    [a13board.kicad_pcb]
2013-04-04 more routing of DDR3
    [a13board.kicad_pcb]
2013-04-05 more routing of ddr3, found smaller approach, bga-escaping VMEM and GND
    [a13board.kicad_pcb]
2013-04-05 reducing space, occupied by address lines
    [a13board.kicad_pcb]
2013-04-06 Fixed some bugs with symbols, tracing continued
    [CPU.sch, DRAM.sch, NAND.sch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]
2013-04-06 Added connectors
    [a13board.kicad_pcb]
2013-04-07 Meeting 5x10 goal
    [a13board.kicad_pcb]
2013-04-08 A bit more of tracing of PCB
    [a13board.kicad_pcb]
2013-04-08 a bit improved layout
    [a13board.kicad_pcb]
2013-04-08 New gerber
    [a13board-B_Cu.gbl, a13board-F_Cu.gtl, a13board-F_SilkS.gto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]
2013-04-08 Almost all escaped from BGA
    [a13board.kicad_pcb]
2013-04-09 Connected a few more connections; BGA escape finished
    [a13board.kicad_pcb]
2013-04-09 Some more traces (for connectors)
    [a13board.kicad_pcb]
2013-04-09 Better naming for gerbers
    [a13board-B_Cu.gbl, a13board-Edge_Cuts.gbr, a13board-F_Cu.gtl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]
2013-04-09 new gerbers
    [a13board-B_Cu.gbl, a13board-Edge_Cuts.gbr, a13board-F_Cu.gtl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]
2013-04-09 Fixed thermal pad on A10
    [a13board.kicad_pcb]
2013-04-09 shiny new gerbers, fixed paste and mask
    [a13board-B_Cu.gbl, a13board-Edge_Cuts.gbr, a13board-F_Cu.gtl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]
2013-04-10 Added thermal for AXP209
    [a13board.kicad_pcb]
2013-04-10 Added better stencil support
    [a13board.kicad_pcb]
2013-04-10 Added missing footprints
    [a13board.kicad_pcb]
2013-04-10 Rearranged pins so to make tracing easier
    [CPU.sch, DRAM.sch, NAND.sch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]
2013-04-10 Using proper module for crystal, some rearrangements regarding connectors
    [a13board.kicad_pcb]
2013-04-11 Experimented with autotracer
    [a13board.kicad_pcb]
2013-04-11 Different layout for connectors
    [CPU.sch, DRAM.sch, NAND.sch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]
2013-04-11 Proper GND fill of thermal pad on AXP209
    [CPU.sch, DRAM.sch, NAND.sch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]
2013-04-15 More power traced
    [a13board.kicad_pcb]
2013-04-15 Added new crystal, changed 2 pins on connectors
    [CPU.sch, DRAM.sch, NAND.sch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]
2013-04-16 Almost finished tracing
    [a13board.kicad_pcb]
2013-04-16 New gerbers and board image
    [a13board-B_Cu.gbl, a13board-Edge_Cuts.gbr, a13board-F_Cu.gtl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]
2013-04-16 A few untraced connections left
    [a13board.kicad_pcb]
2013-04-16 All traces traced...
    [a13board.kicad_pcb]
2013-04-16 New gerber and png file
    [a13board-B_Cu.gbl, a13board-Edge_Cuts.gbr, a13board-F_Cu.gtl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]
2013-04-16 Updated to people's suggestions
    [a13board-B_Cu.gbl, a13board-Edge_Cuts.gbr, a13board-F_Cu.gtl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]
2013-04-16 Updated to proper zone fill
    [a13board-B_Cu.gbl, a13board-Edge_Cuts.gbr, a13board-F_Cu.gtl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]
2013-04-17 Updated layout with people's suggestions
    [CPU.sch, DRAM.sch, NAND.sch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]
2013-04-18 Used polygon for power pins
    [a13board.kicad_pcb]
2013-04-18 Included all layers to gerber project, improved .png
    [a13board-B_Cu.gbl, a13board-Edge_Cuts.gbr, a13board-F_Cu.gtl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]
2013-04-19 Fixed some power issues
    [a13board-B_Cu.gbl, a13board-Edge_Cuts.gbr, a13board-F_Cu.gtl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]
2013-04-19 A little fit of border clearance fixed
    [a13board.kicad_pcb]
2013-04-20 Added new gerber files and png
    [a13board-B_Cu.gbl, a13board-Edge_Cuts.gbr, a13board-F_Cu.gtl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]
2013-04-20 Improved data lines
    [a13board.kicad_pcb]
2013-04-21 Fixed some symbols, hidden some silk
    [a13board.kicad_pcb]
2013-04-21 Added proper gerber layers, fixed .dri file, some fixes of silk
    [a13board-B_Cu.gbl, a13board-B_Mask.gbs, a13board-B_Paste.gbp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]
2013-04-22 Updated for paste
    [a13board.kicad_pcb]
2013-04-22 Fixed stencil apertures
    [a13board.kicad_pcb]
2013-04-22 Fixed stencil apertures (gerbers)
    [a13board-B_Cu.gbl, a13board-B_Mask.gbs, a13board-B_Paste.gbp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]
2013-07-02 Added BOM
    [a13board.csv]
2013-07-02 Added BOM pdf
2014-05-16 Layout improvements, NPTH holes
    [a13board-B_Cu.gbl, a13board-B_Mask.gbs, a13board-B_Paste.gbp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]
